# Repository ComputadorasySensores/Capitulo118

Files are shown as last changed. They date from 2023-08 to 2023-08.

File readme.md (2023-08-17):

# Pico Carrier

Un placa de desarrollo simple para Raspberry Pi Pico/W que incorpora la posibilidad de conectar una pantalla OLED SSD1306 (con jumpers para diferentes variantes de alimentación) y un sensor ambiental BMP/BME280.
También expone todos los GPIO de la placa para una fácil conexión de dispositivos adicionales y un pulsador de reset.

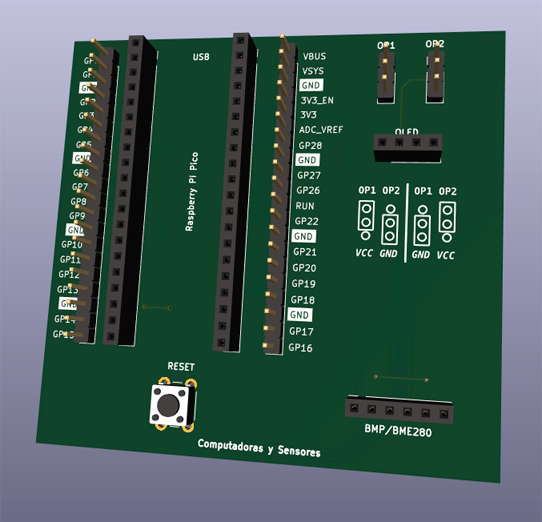
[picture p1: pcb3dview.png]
PCB3DView


Todos los archivos de diseño en Kicad se encuentran publicados junto a un código de ejemplo en MicroPython

# Fabricación

Dentro de la carpeta `fab` encontrarás los archivos individuales Gerber y de perforación, también el archivo `Pico-Carrier-Fab.zip` que incluye todo listo para ordenar a tu fabricante de PCB favorito.

# Paso a paso

La explicación completa la podrás ver en el siguiente video de Youtube:
https://youtu.be/Y6Xd9Z1UVGs

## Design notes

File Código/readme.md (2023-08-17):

# Programa de ejemplo

El programa de ejemplo `main.py` para ejecutar desde la Raspberry Pi Pico/W requiere las siguientes librerías:
- https://github.com/robert-hh/BME280
- https://github.com/stlehmann/micropython-ssd1306

# Paso a paso

La explicación completa la podrás ver en el siguiente video de Youtube:
https://youtu.be/Y6Xd9Z1UVGs

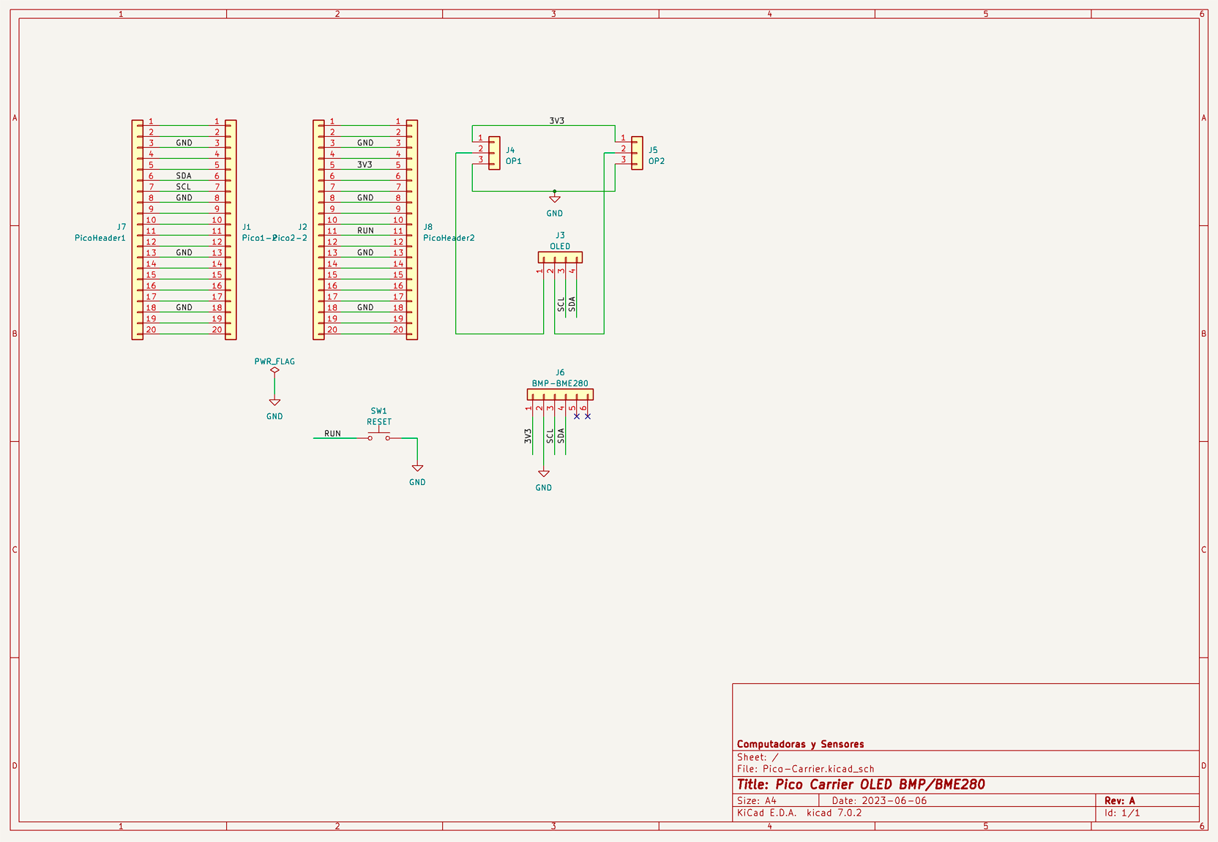
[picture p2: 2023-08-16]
esquematico.png

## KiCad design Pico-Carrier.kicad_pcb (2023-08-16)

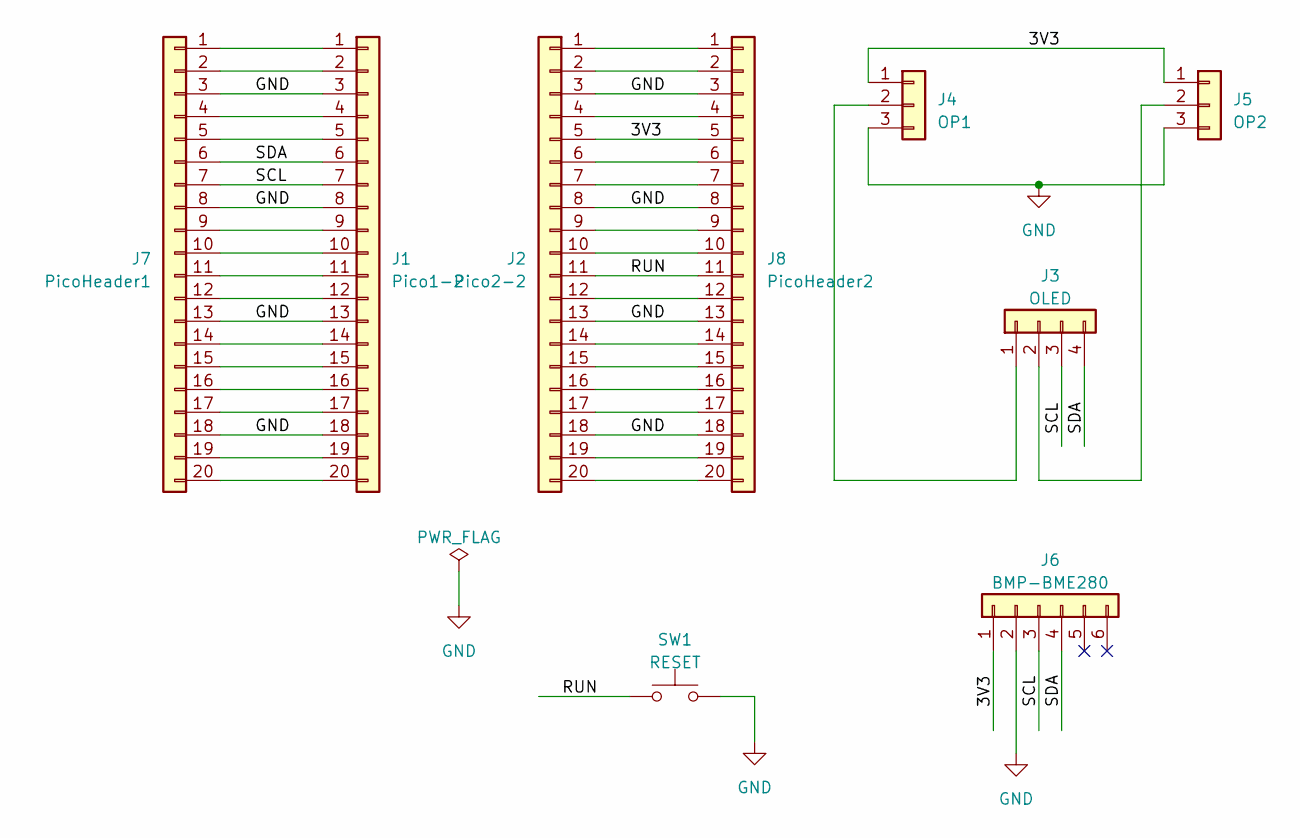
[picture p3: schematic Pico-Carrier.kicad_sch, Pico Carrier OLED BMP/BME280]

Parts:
J1: Pico1-2; PinSocket_1x20_P2.54mm_Vertical
J2: Pico2-2; PinSocket_1x20_P2.54mm_Vertical
J3: OLED; PinSocket_1x04_P2.54mm_Vertical
J4: OP1; PinHeader_1x03_P2.54mm_Vertical
J5: OP2; PinHeader_1x03_P2.54mm_Vertical
J6: BMP-BME280; PinSocket_1x06_P2.54mm_Vertical
J7: PicoHeader1; PinHeader_1x20_P2.54mm_Vertical
J8: PicoHeader2; PinHeader_1x20_P2.54mm_Vertical
SW1: RESET; SW_PUSH_6mm

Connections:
/3V3: J2.5, J4.1, J5.1, J6.1, J8.5
/RUN: J2.11, J8.11, SW1.1
/SCL: J1.7, J3.3, J6.3, J7.7
/SDA: J1.6, J3.4, J6.4, J7.6
GND: J1.3, J1.8, J1.13, J1.18, J2.3, J2.8, J2.13, J2.18, J4.3, J5.3, J6.2, J7.3, J7.8, J7.13, J7.18, J8.3, J8.8, J8.13, J8.18, SW1.2
unnamed: J1.1, J7.1
unnamed: J1.2, J7.2
unnamed: J1.4, J7.4
unnamed: J1.5, J7.5
unnamed: J1.9, J7.9
unnamed: J1.10, J7.10
unnamed: J1.11, J7.11
unnamed: J1.12, J7.12
unnamed: J1.14, J7.14
unnamed: J1.15, J7.15
unnamed: J1.16, J7.16
unnamed: J1.17, J7.17
unnamed: J1.19, J7.19
unnamed: J1.20, J7.20
unnamed: J2.1, J8.1
unnamed: J2.2, J8.2
unnamed: J2.4, J8.4
unnamed: J2.6, J8.6
unnamed: J2.7, J8.7
unnamed: J2.9, J8.9
unnamed: J2.10, J8.10
unnamed: J2.12, J8.12
unnamed: J2.14, J8.14
unnamed: J2.15, J8.15
unnamed: J2.16, J8.16
unnamed: J2.17, J8.17
unnamed: J2.19, J8.19
unnamed: J2.20, J8.20
unnamed: J3.1, J4.2
unnamed: J3.2, J5.2

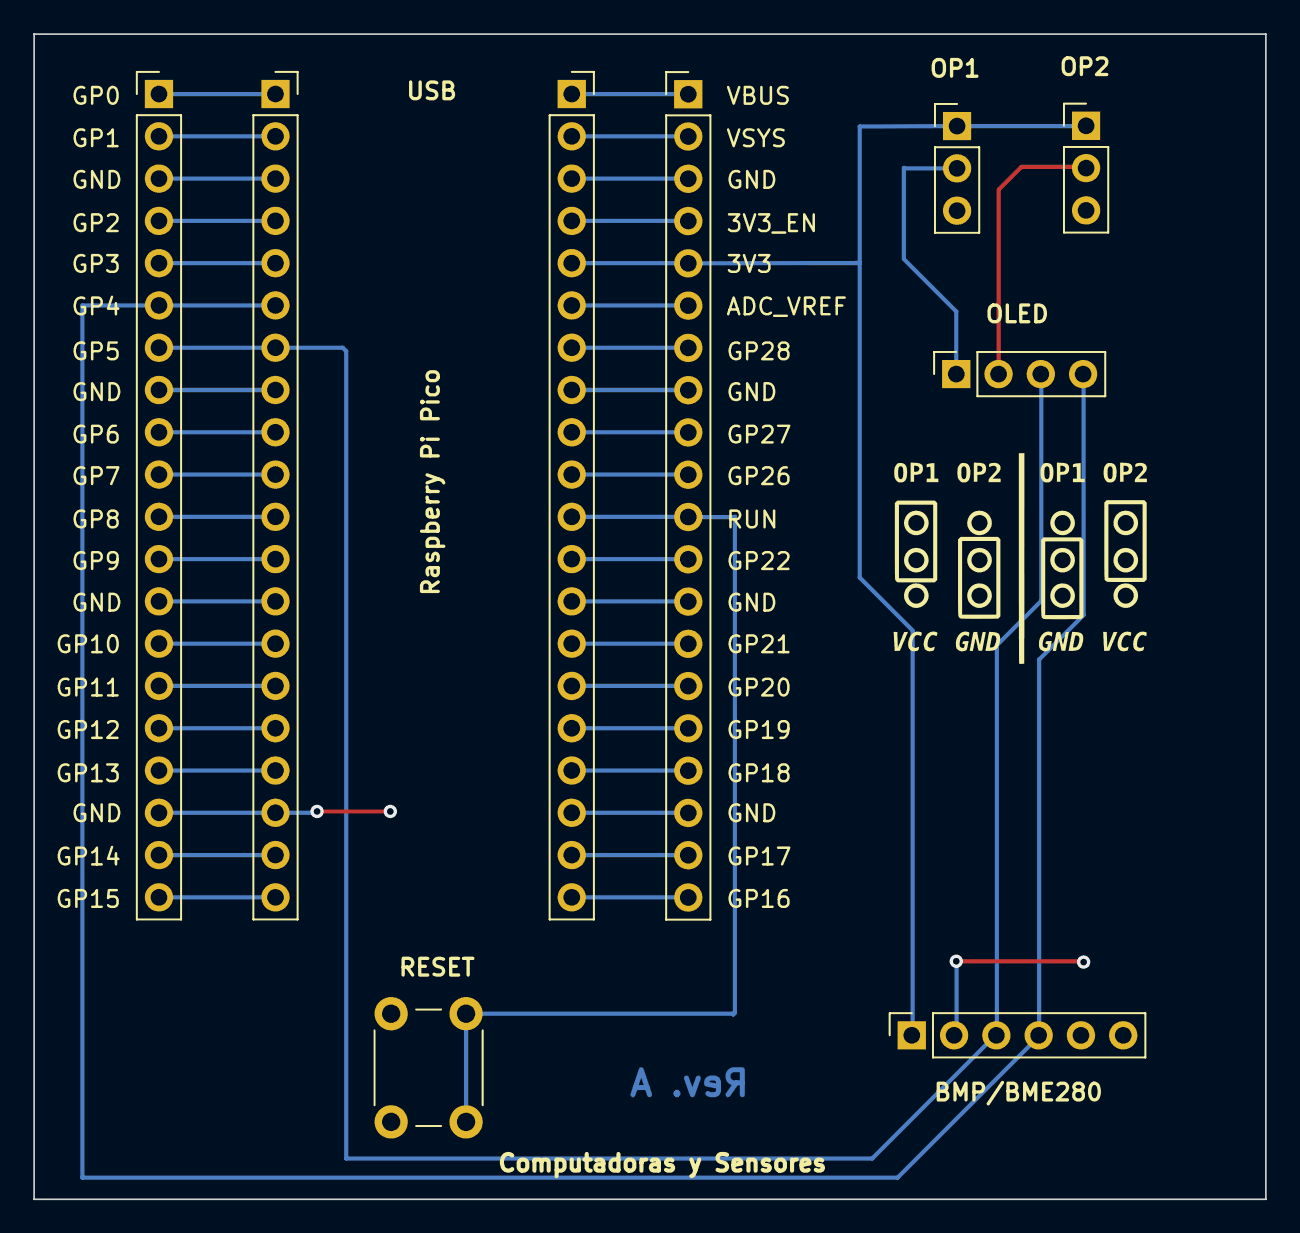
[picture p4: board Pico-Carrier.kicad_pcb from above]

Board: 2 copper layers, 74.0 x 70.0 mm, 9 parts (0 on the bottom side), 35 nets.

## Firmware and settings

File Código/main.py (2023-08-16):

from machine import Pin, I2C
import time
import bme280
from ssd1306 import SSD1306_I2C

i2c=I2C(0,sda=Pin(4), scl=Pin(5), freq=400000)

bme = bme280.BME280(i2c=i2c)

oled = SSD1306_I2C(128, 64, i2c)
oled.fill(0)
oled.text("Computadoras", 20, 20)
oled.text("y", 60, 35)
oled.text("Sensores", 35, 50)
oled.show()
time.sleep(2)

while (True):
    temp = bme.values[0]
    pres = bme.values[1]
    hum = bme.values[2]
    
    oled.fill(0)
    #print(bme.values)
    oled.text("Datos ambiente", 10, 0)
    oled.text("Temp: " + temp, 0, 18)
    oled.text("Hum:  " + hum, 0, 37)
    oled.text("Pres: " + pres, 0, 56)
    oled.show()
    time.sleep(2)

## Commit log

2023-08-16 Update and rename jumpers_oled.kicad_mod to Graficos.pretty/jumpers_oled.kicad_mod
2023-08-16 Update and rename Pico-Carrier-B_Cu.gbr to fab/Pico-Carrier-B_Cu.gbr
    [Pico-Carrier-B_Cu.gbr]
2023-08-16 Update and rename Pico-Carrier-B_Mask.gbr to fab/Pico-Carrier-B_Mask.gbr
    [Pico-Carrier-B_Mask.gbr]
2023-08-16 Update and rename Pico-Carrier-Edge_Cuts.gbr to fab/Pico-Carrier-Edge_Cuts.gbr
    [Pico-Carrier-Edge_Cuts.gbr]
2023-08-16 Update and rename Pico-Carrier-F_Cu.gbr to fab/Pico-Carrier-F_Cu.gbr
    [Pico-Carrier-F_Cu.gbr]
2023-08-16 Update and rename Pico-Carrier-F_Mask.gbr to fab/Pico-Carrier-F_Mask.gbr
    [Pico-Carrier-F_Mask.gbr]
2023-08-16 Update and rename Pico-Carrier-F_Silkscreen.gbr to fab/Pico-Carrier-F_Silkscreen.gbr
    [Pico-Carrier-F_Silkscreen.gbr]
2023-08-16 Update and rename Pico-Carrier-NPTH.drl to fab/Pico-Carrier-NPTH.drl
    [Pico-Carrier-NPTH.drl]
2023-08-16 Update and rename Pico-Carrier-PTH.drl to fab/Pico-Carrier-PTH.drl
    [Pico-Carrier-PTH.drl]
2023-08-16 Update and rename Pico-Carrier-job.gbrjob to fab/Pico-Carrier-job.gbrjob
    [Pico-Carrier-job.gbrjob]
